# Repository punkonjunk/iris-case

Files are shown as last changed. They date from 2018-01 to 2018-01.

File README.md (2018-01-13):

Original text for the readme below. I've added into this uh, git hub thing the 3d printable files I generated from keebio's AI files. They all work. Also on thingiverse: https://www.thingiverse.com/thing:2728375

Iris Keyboard Case
==================

Here's case design files for the [Iris](https://keeb.io/products/iris-keyboard-split-ergonomic-keyboard). It's a sandwich-style case with cutouts to accomodate the USB jack and the TRRS jack.

Case pieces
-----------

- Switch layer (`iris-switch-plate.ai`)
- Bottom layer (`iris-bottom-plate.ai`)
- Middle layer (`iris-middle-layer.ai`)

Screws and Standoffs
--------------------
This case was designed to use M2 screws and standoffs. The holes in the middle layers are for the standoffs, while the holes in the top and bottom layers are only wide enough for the screws. M2 screws and standoffs that fit the case can be purchased at Keebio: [M2 Screws & Standoffs](https://keeb.io/products/m2-screws-and-standoffs)

Fabrication
-----------

### Sculpteo
[Sculpteo](https://www.sculpteo.com) offers laser cutting services and is relatively easy to use.

Steps:
- Upload file
- Scale the object correctly, the dimensions of the plates are 153.7mm x 133.9mm
- Make sure all colors are set to "Cut" and not any of the engraving choices
- Select your material and order

### Ponoko
To have the case made with Ponoko, you can't take these files as is and send them off to them. First, you'll need to download the templates for P1, P2, & P3 sheets from here, depending on what vector editor you are using:

- [Inkscape templates](https://www.ponoko.com/starter-kits/inkscape)
- [Adobe Illustrator template](https://www.ponoko.com/starter-kits/adobe-illustrator)
- [Other](https://www.ponoko.com/make-and-sell/design-it-yourself)

Next, open up the template of the sheet size you want and open up the case design files as well. Then, copy the drawings in the case design files into the template. Remove any overlapping lines to reduce the cutting cost using this guide: [Avoid doubled up lines](http://support.ponoko.com/hc/en-us/articles/220289608-Avoid-doubled-up-blue-cutting-lines-in-your-designs).

### Middle Layer Thickness
If you're having the middle layers made, from the top of the switch plate to the top of the bottom plate, the minimium distance between the two required is 12mm if the plastic on the header pins is removed. The requirement is slightly more (about 13.5mm) if you leave the plastic on. Therefore, the following middle layer thickness are needed based on the thickness of the switch layer:

- 1.5mm Stainless steel switch plate: 10.5mm
    - Usually accomplished with:
        - 2x4.5mm + 1x1.5mm layers
        - or 3x3mm + 1x1.5mm layers
        - or 4x3mm layers
- 3mm acrylic switch plate: 9mm
    - Usually accomplished with:
        - 2x4.5mm layers
        - or 3x3mm layers

License
-------
These case files are released under the MIT License.

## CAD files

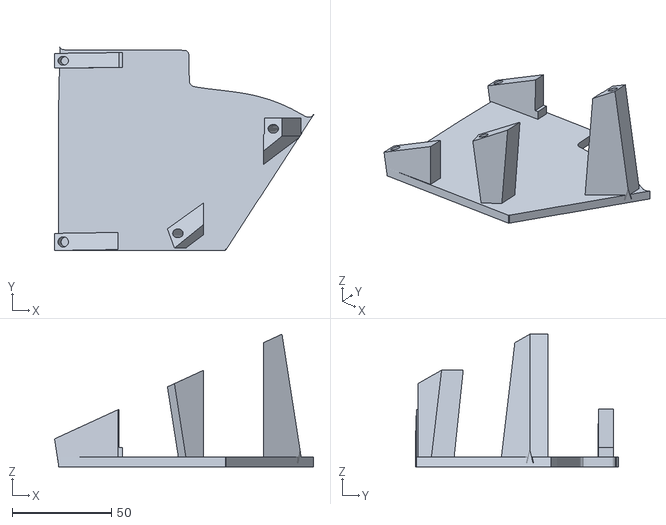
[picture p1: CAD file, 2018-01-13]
wrist rest full hand unbranded.stl
130.8 x 102.5 x 67.0

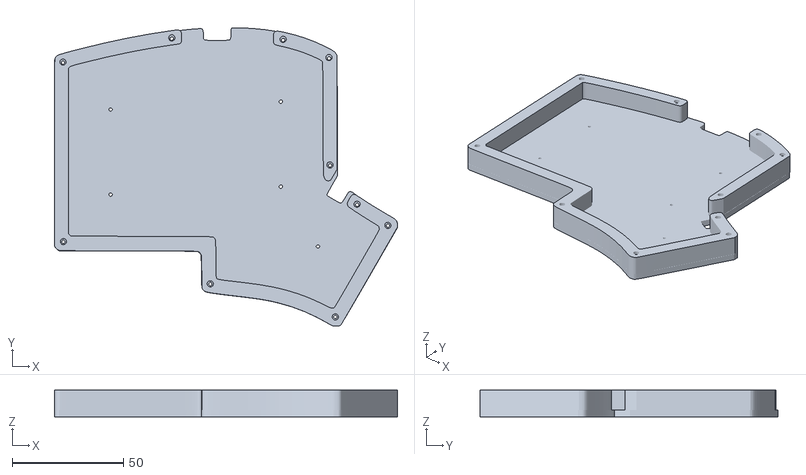
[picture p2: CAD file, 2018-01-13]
bottom plate plate with walls.stl
154.0 x 134.0 x 12.0

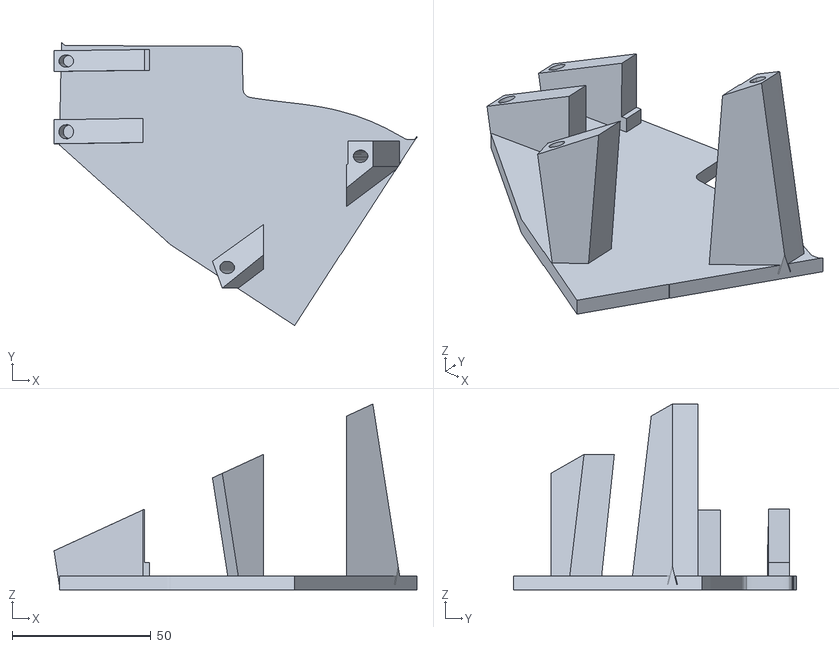
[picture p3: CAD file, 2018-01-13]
wrist rest shorty.stl
130.8 x 102.0 x 67.0

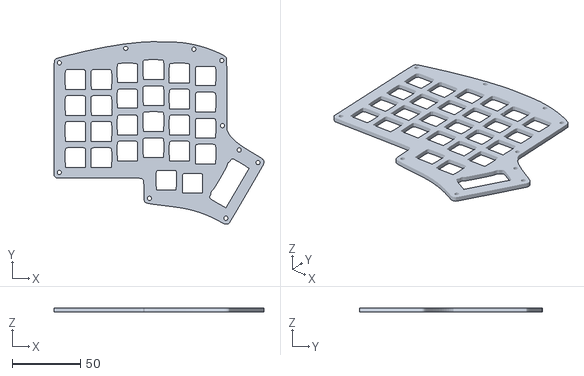
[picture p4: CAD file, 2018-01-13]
plate.stl
153.8 x 133.7 x 3.00

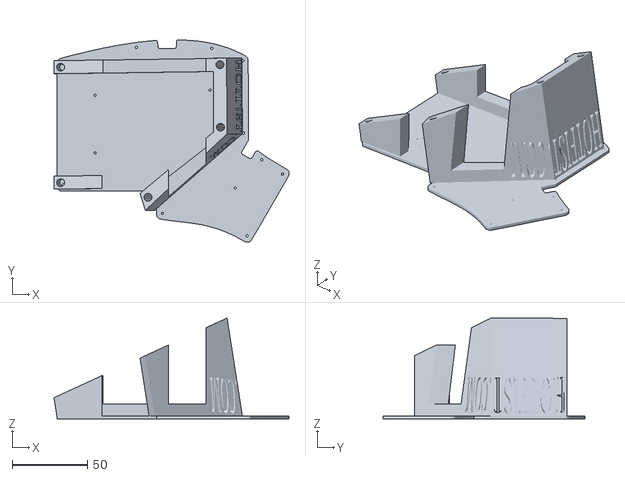
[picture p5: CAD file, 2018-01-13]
hotfist branded tent dualfoot.stl
155.9 x 134.1 x 67.0

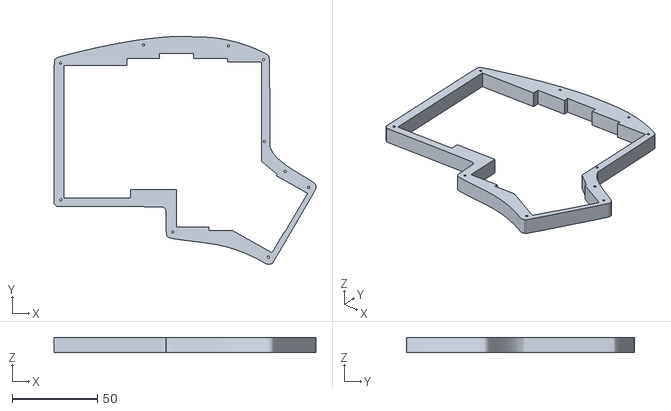
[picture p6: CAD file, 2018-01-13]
hipro plate addon.stl
153.8 x 133.7 x 9.00

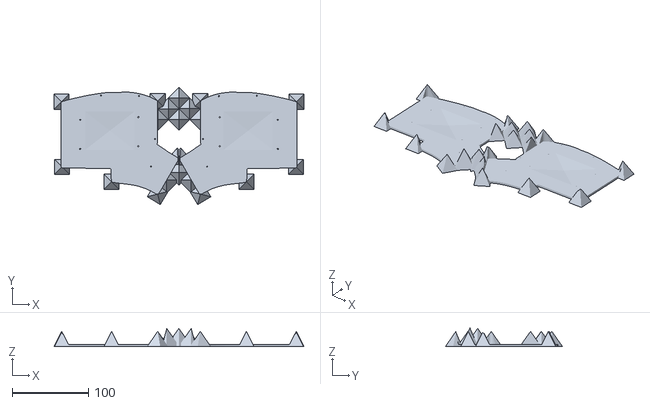
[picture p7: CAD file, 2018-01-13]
batwing iris holder exp.stl
328.6 x 154.0 x 23.9

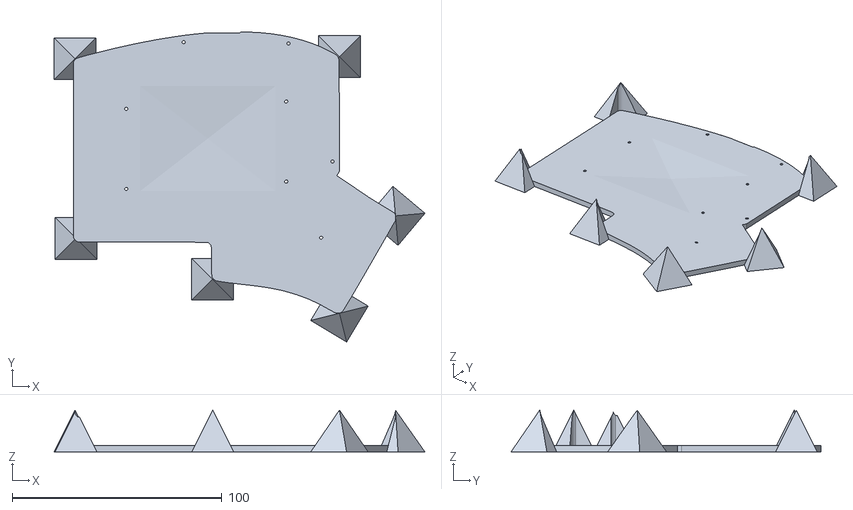
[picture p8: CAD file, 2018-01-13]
pyramid grippy tent holder.stl
177.1 x 148.0 x 20.0
